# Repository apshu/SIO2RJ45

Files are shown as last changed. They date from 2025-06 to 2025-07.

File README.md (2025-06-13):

# SIO2RJ45
Converter PCB from Atari SIO to RJ45, with optional SIO2PC feature.

RJ45 is commonly used by Ethernet UTP cable

## Features
- STL files for housing
- SIO2PC function with optional USB to serial module
- Open-drain configuration for safe operation
- Separated +5V from SIO and USB. Allowing more power for RJ45 peripherals
- Audio, motor, Serial in/out and power are put to the Ethernet connector

## Folders

| Folder | Description |
|---|---|
| [PCB source](/PCB%20source/) |  KiCAD Schematics and PCB files |
| [3D source](/3D%20source/) |  Files for 3d casing |
| [release](/release/) |  Manufacturing files needed for building the project |

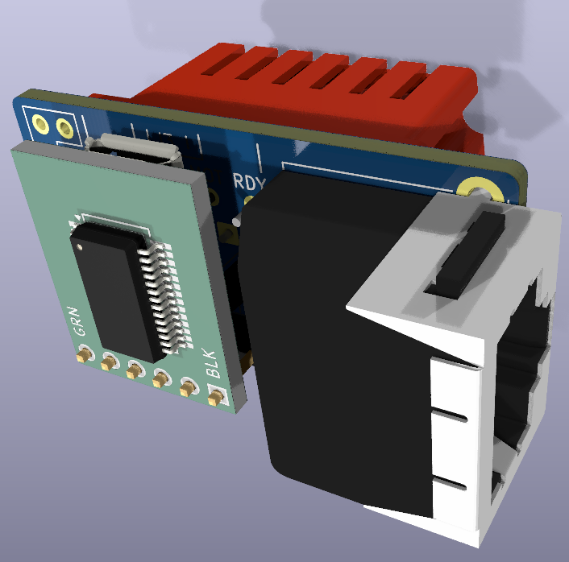
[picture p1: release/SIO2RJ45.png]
SIO2RJ45


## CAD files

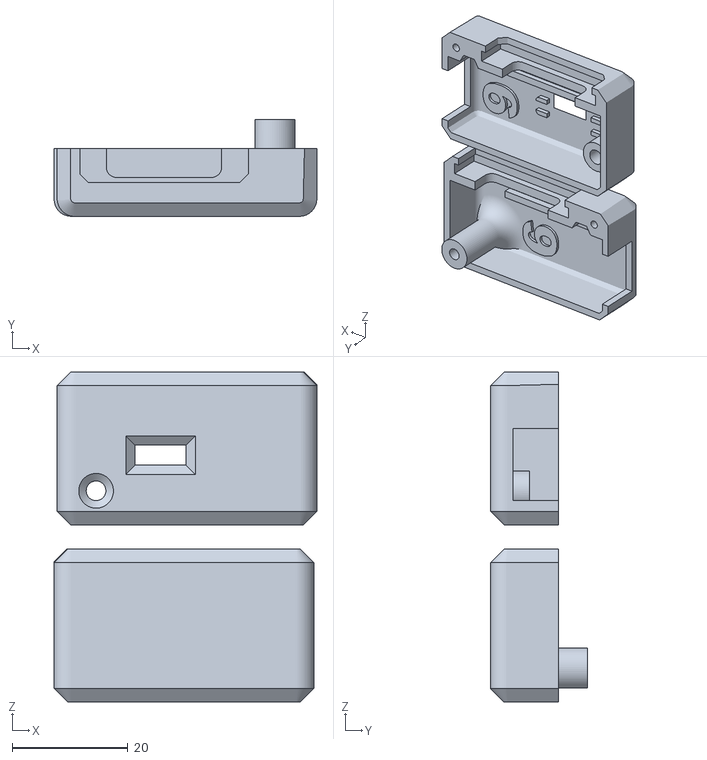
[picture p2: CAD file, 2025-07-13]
release/SIO2RJ45_housing.stl
45.4 x 16.8 x 57.0

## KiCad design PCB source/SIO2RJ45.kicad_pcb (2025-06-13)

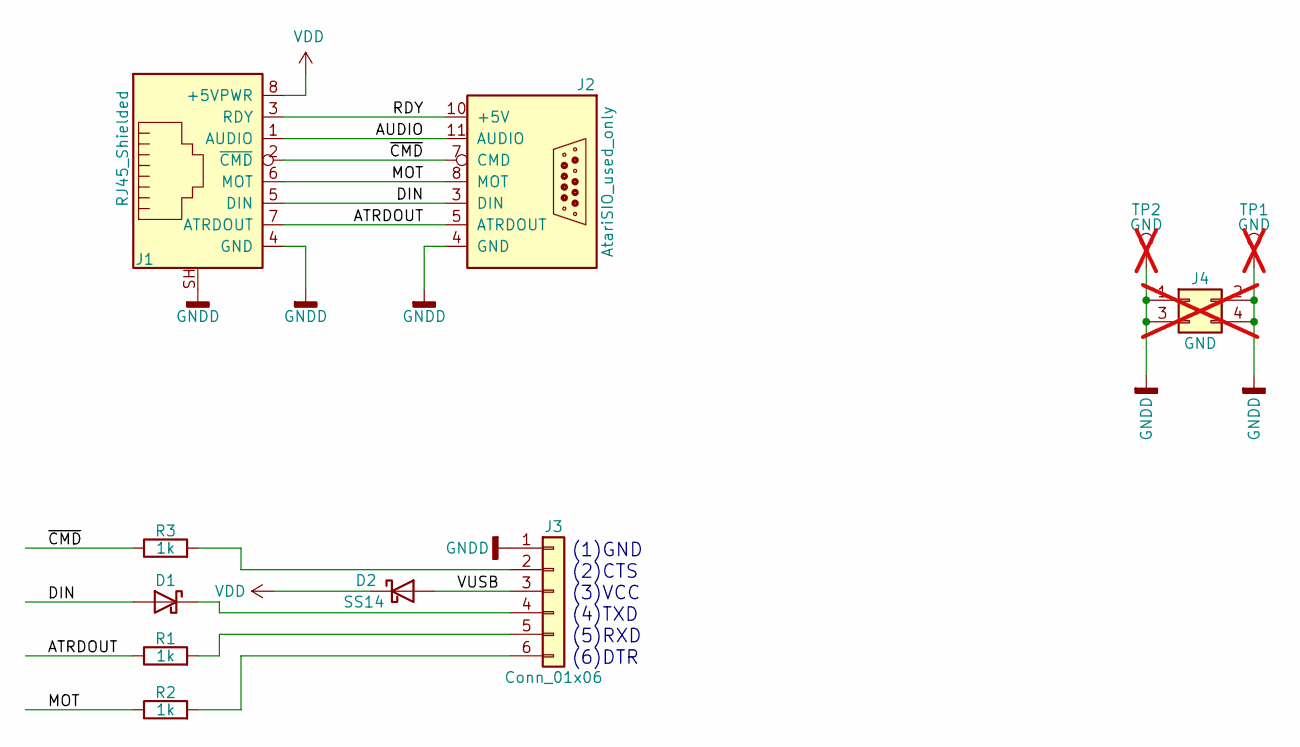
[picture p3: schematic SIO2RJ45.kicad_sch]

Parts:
D1: D_Schottky; D_A-405_P10.16mm_Horizontal
D2: SS14; D_SMA
J1: RJ45_Shielded; RJ45_Ninigi_GE
J2: AtariSIO_used_only; SIO_vertical_used_only
J3: Conn_01x06; PinHeader_1x06_P2.54mm_Vertical
J4: GND; PinHeader_2x02_P2.54mm_Vertical; not fitted
R1, R2, R3: 1k; R_0805_2012Metric_Pad1.20x1.40mm_HandSolder
TP1, TP2: GND; TestPoint_Loop_D2.60mm_Drill1.6mm_Beaded; not fitted

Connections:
/ATRDOUT: J1.7 (ATRDOUT), J2.5 (ATRDOUT), R1.1
/AUDIO: J1.1 (AUDIO), J2.11 (AUDIO)
/DIN: D1.2 (A), J1.5 (DIN), J2.3 (DIN)
/MOT: J1.6 (MOT), J2.8 (MOT), R2.1
/RDY: J1.3 (RDY), J2.10 (+5V)
/VUSB: D2.2 (A), J3.3
/~CMD: J1.2 (~CMD), J2.7 (CMD), R3.1
GNDD: J1.4 (GND), J1.SH, J2.4 (GND), J2.6 (GND), J3.1, J4.1, J4.2, J4.3, J4.4, TP1.1, TP2.1
unnamed: D1.1 (K), J3.4
unnamed: J3.2, R3.2
unnamed: J3.5, R1.2
unnamed: J3.6, R2.2
VDD: D2.1 (K), J1.8 (+5VPWR)

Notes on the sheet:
(1)GND (2)CTS (3)VCC (4)TXD (5)RXD (6)DTR

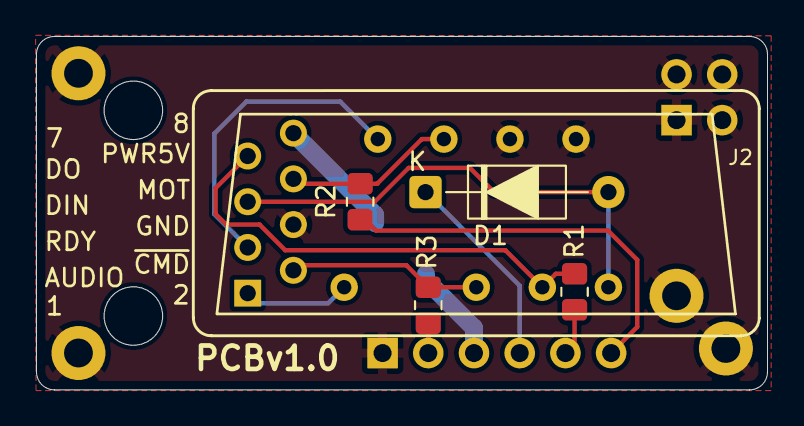
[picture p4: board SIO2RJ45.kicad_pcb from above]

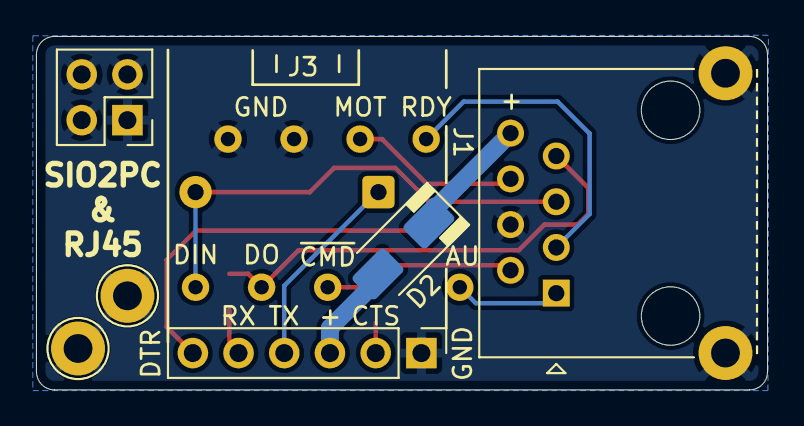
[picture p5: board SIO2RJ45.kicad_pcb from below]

Board: 2 copper layers, 40.6 x 19.6 mm, 11 parts (6 on the bottom side), 13 nets.

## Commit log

2025-06-13 PCB files
    [SIO2RJ45.kicad_pcb, SIO2RJ45.kicad_sch]
2025-07-13 Housing 3D design and printable STL
    [SIO2RJ45_houseing.stl]
2025-07-13 Typo in file name corrected
    [SIO2RJ45_housing.stl]
